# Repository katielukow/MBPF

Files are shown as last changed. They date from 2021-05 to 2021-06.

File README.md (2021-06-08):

# Modular Battery Pressure Fixture (MBPF)

**Background**

The High Voltage and Energy Storage Group (HVES) is a research group within the School of Engineering, Computing, and Mathematics at Oxford Brookes University. The group focuses is developing novel solutions to problems within the energy storage and future of transport fields. This includes multi-scale numerical modelling, electrochemical testing of lithium-ion batteries, and optimal control research for battery management and high-voltage powertrain systems. The group also has experience in optimal high power battery pack design and second-life applications of packs. Additional information can be found at https://hves.brookes.ac.uk. As part of the electrochemical testing, a fixture was designed to apply pressure to the outside faces of a lithium-ion pouch cell to provide a more accurate use case when completing cell level testing.

MBPF-Render-Asm

**Fixture Overview**

The fixture is a modular design that can accommodate cells that are 36mm to 50mm wide and 125mm to 145mm long. Pressure is applied to the cell through a double top plate that has Flexiforce sensors in between to map out the pressure distribution. A total of 14 M5 hex head screws are available to create the desired distribution based on the pressure and cell geometry being used. Nylon dowels are used to position the cell in place.

assemblyexplodedview

Two busbars are clamped onto the battery tabs with M6 bronze fasteners for current load and there is a gold-plated copper piece for voltage sensing. Current development is looking at creating additional lower bus bar designs to account for higher current loads with M8 fasteners.There is a grid system for thermocouples to be placed at various locations across the cell surface.

thermocouplechannel

**Exploded View & Bill of Materials**

An exploded view of the assembly can be found in the image below with a bill of materials available in the table below.

fullassemblyexploded
  
| Part Number | Part Name | Quantity |
| :---: | :---: | :---: |
| HVES-FIX-PRES-01  | Pouch Pressure Fixture - Top | 2 |
| HVES-FIX-PRES-02  | Pouch Pressure Fixture - Bottom | 1 |
| HVES-FIX-PRES-03  | Copper Clamp - Bottom | 2 |
| HVES-FIX-PRES-04  | Copper Clamp - Top | 2 |
| HVES-FIX-PRES-05  | Clamp Holder| 1 |
| HVES-FIX-PRES-07  | Voltage Sensing Plate | 2 |
| HVES-FIX-PRES-08  | Tab Separator | 1 |
| N/A  | M2.5X0.45 Grub Screw - 6mm Long | 8 |
| N/A  | M3X0.5 Button Head Cap Screw - 6mm Long | 2 |
| N/A  | M3X0.5 Button Head Cap Screw - 10mm Long | 8 |
| N/A  | M4X0.7 Button Head Cap Screw - 10mm Long | 4 |
| N/A  | M4X0.7 Hex Head Bolt - 60mm Long | 4-14 |
| N/A  | M4X0.7 Hex Nut | 4 |
| N/A  | M5X0.8 Button Head Cap Screw - 25mm Long | 1 |
| N/A  | M5X0.8 Hex Nut | 1 |
| N/A  | M6X1.0 Brass Hex Head Bolt - 25mm Long | 2 |
| N/A  | M6 Brass Spring Washer | 2 |
| N/A  | M6X1.0 Brass Hex Nut | 2 |
| N/A  | 3mm X 6mm Long Nylon Dowel | 7 |

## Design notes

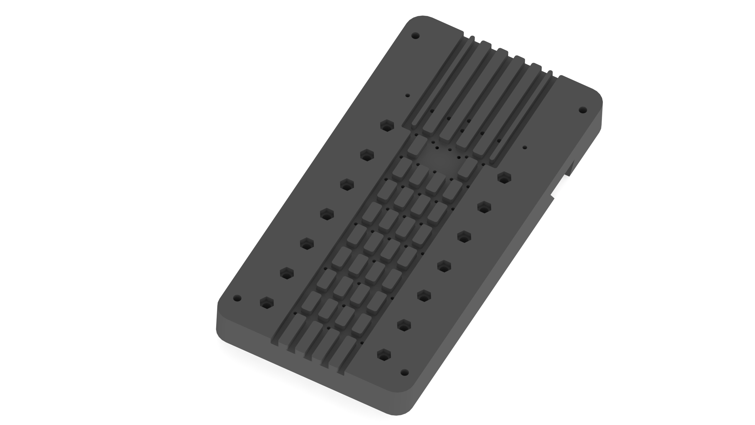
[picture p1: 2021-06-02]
renders/thermocouplechannel.jpg

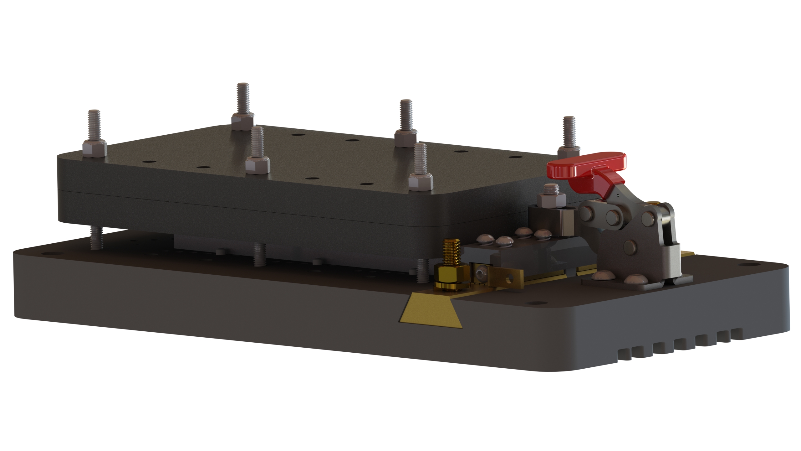
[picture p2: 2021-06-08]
renders/MBPF-Render-Asm.JPG

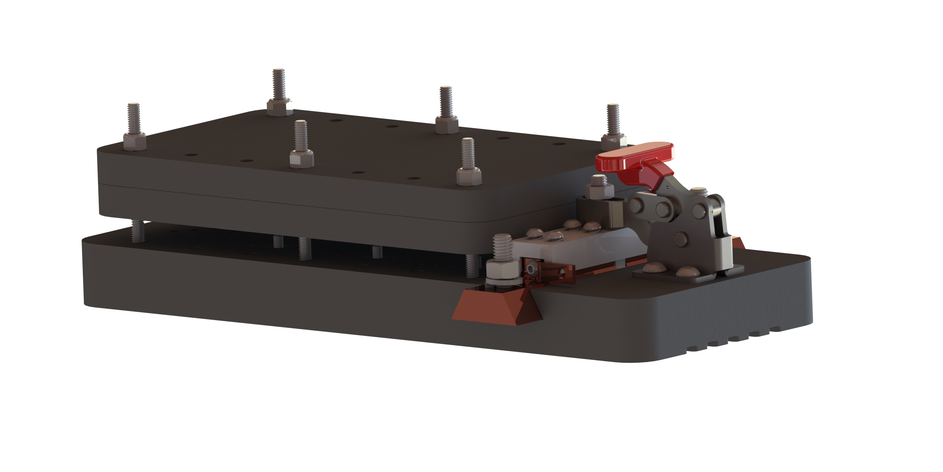
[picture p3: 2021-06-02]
renders/MBPF-Render.jpeg

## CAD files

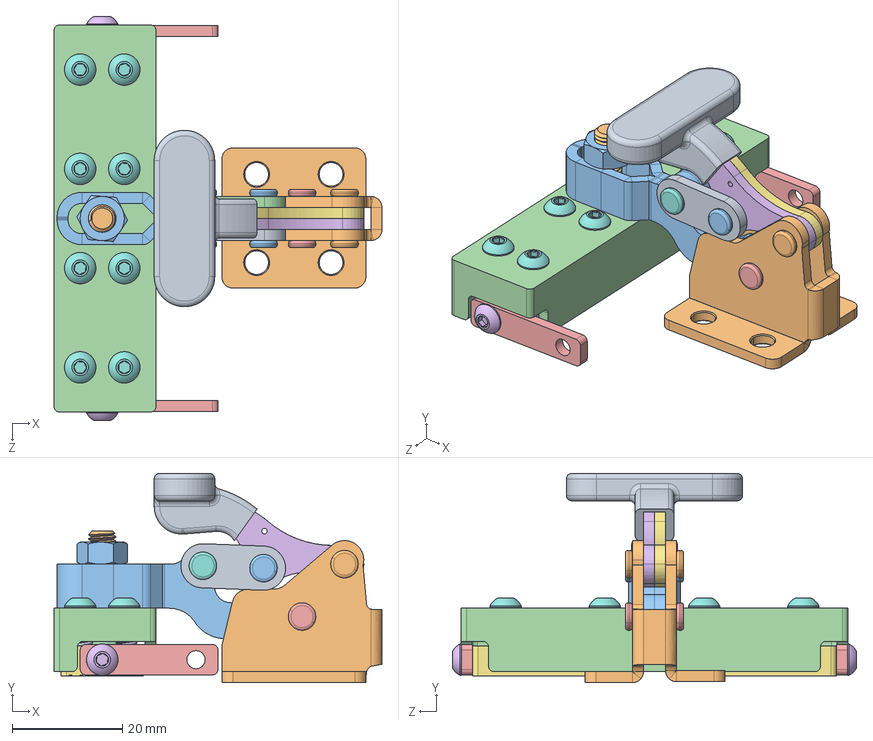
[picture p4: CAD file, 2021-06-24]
CAD/Toggle Clamp Sub Assembly.SLDASM
59.5 x 38.0 x 73.3 mm
Clamp Holder - Single
Voltage Sensing Plate - Flat x 2
92095A179_BUTTON HEAD HEX DRIVE SCREW x 2
Copper Clamp Top x 2
92095A182_BUTTON HEAD HEX DRIVE SCREW x 8
LeeSpring-LCM055B 02 M x 8
92095A481_BUTTON HEAD HEX DRIVE SCREW
90592A095_STEEL HEX NUT

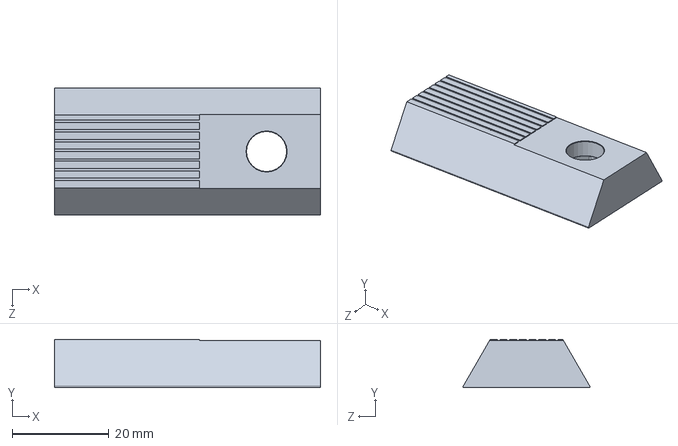
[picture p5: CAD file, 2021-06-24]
CAD/Copper Clamp Bottom.SLDPRT
55.0 x 10.0 x 26.2 mm

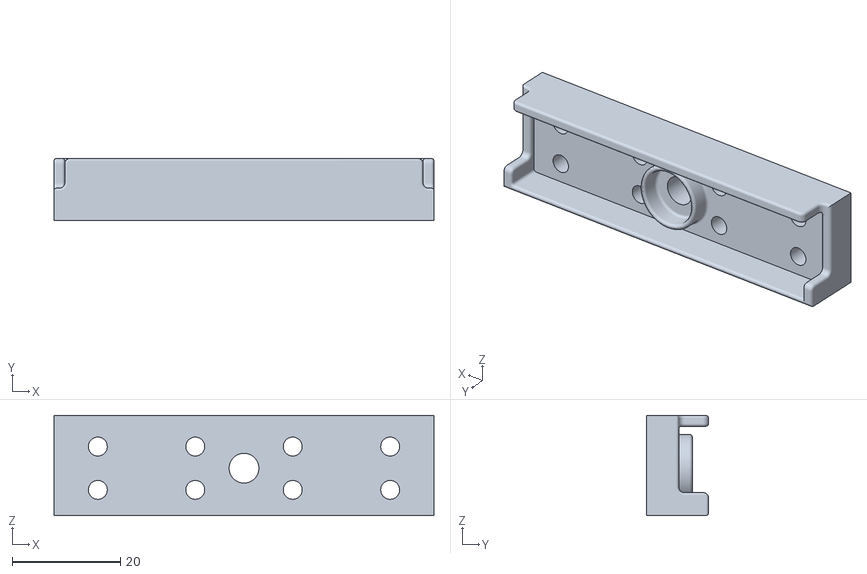
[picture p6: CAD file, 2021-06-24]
stl/HVES-FIX-PRES-05 R1.STL
70.2 x 11.5 x 18.5

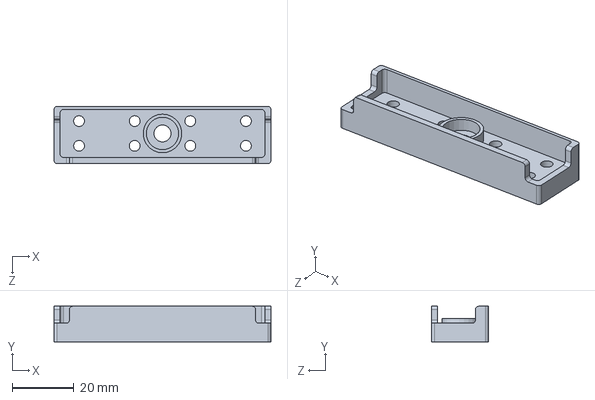
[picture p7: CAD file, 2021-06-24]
CAD/Clamp Holder - Single.SLDPRT
70.2 x 11.5 x 18.5 mm

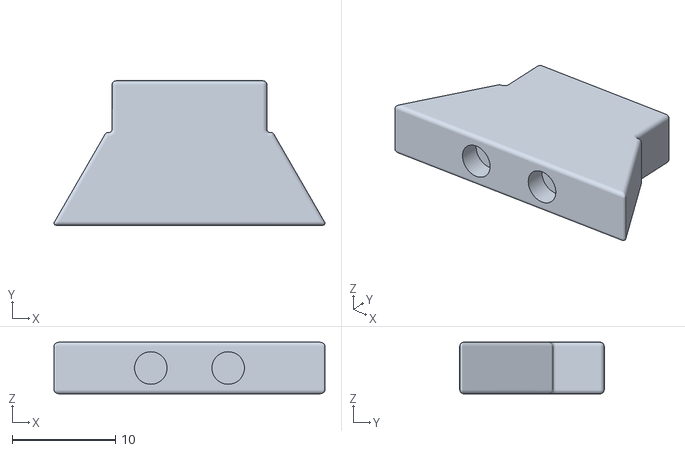
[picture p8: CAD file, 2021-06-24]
stl/HVES-FIX-PRES-08 R0.STL
26.2 x 14.0 x 5.00

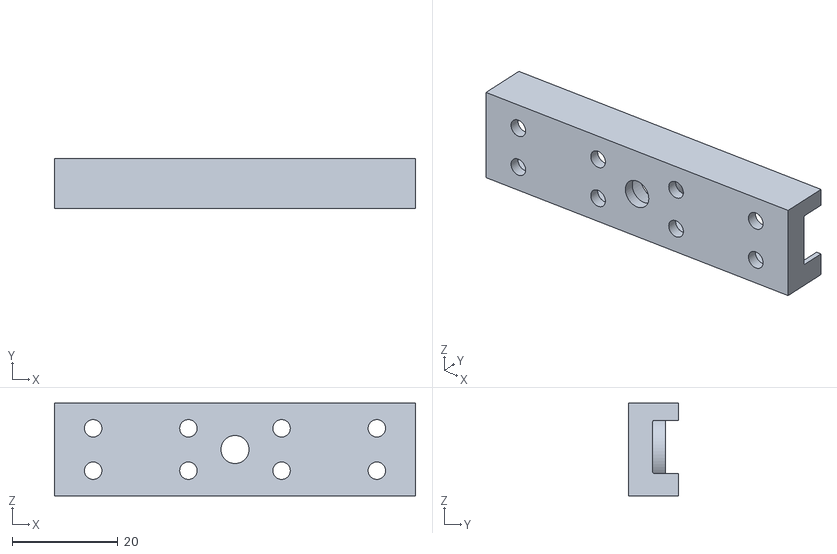
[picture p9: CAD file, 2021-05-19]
stl/HVES-FIX-PRES-05 R0.STL
68.2 x 9.50 x 17.5

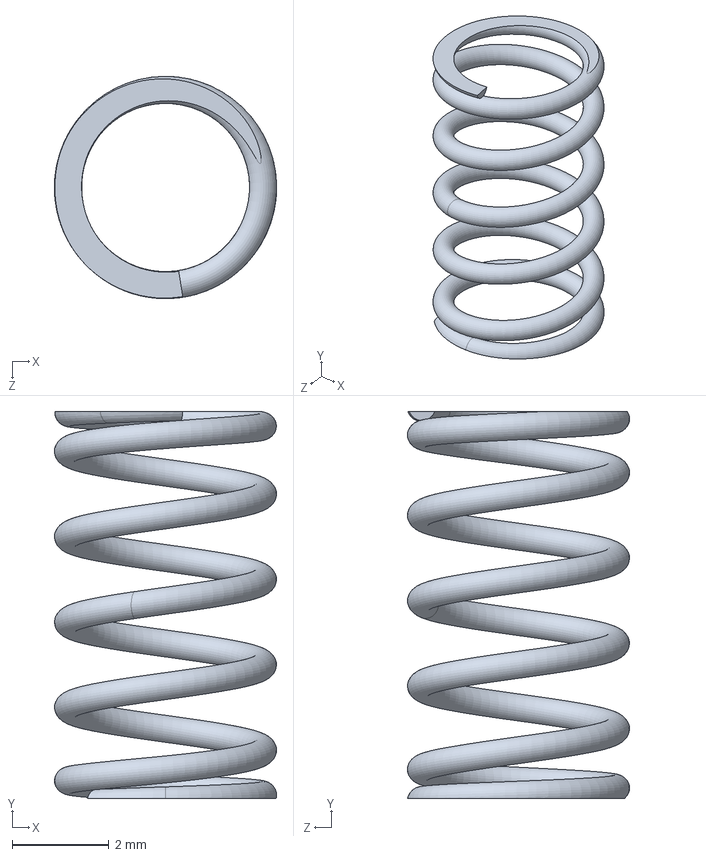
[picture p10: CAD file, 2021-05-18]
CAD/Fastener CAD/LeeSpring-LCM055B 02 M.SLDPRT
4.60 x 8.00 x 4.60 mm

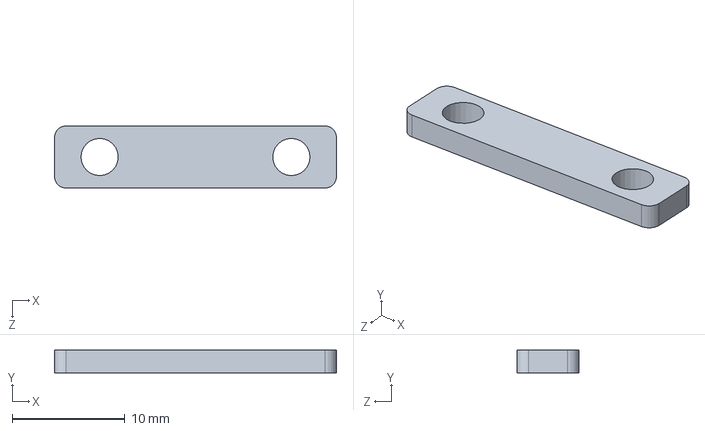
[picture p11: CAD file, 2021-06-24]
CAD/Voltage Sensing Plate - Flat.SLDPRT
25.0 x 2.00 x 5.50 mm

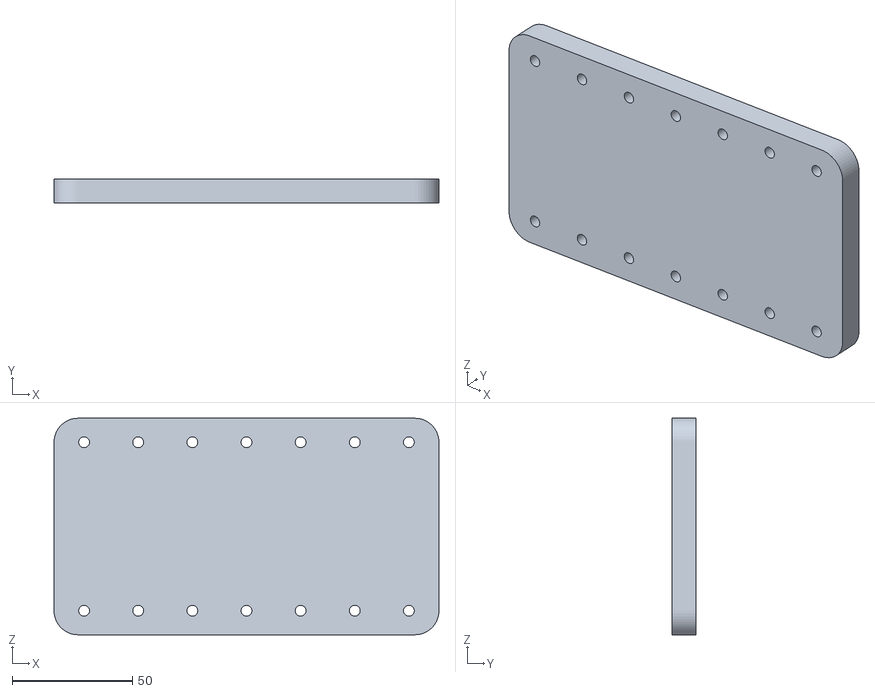
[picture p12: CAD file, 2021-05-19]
stl/HVES-FIX-PRES-01 R0.STL
160.0 x 10.0 x 90.0

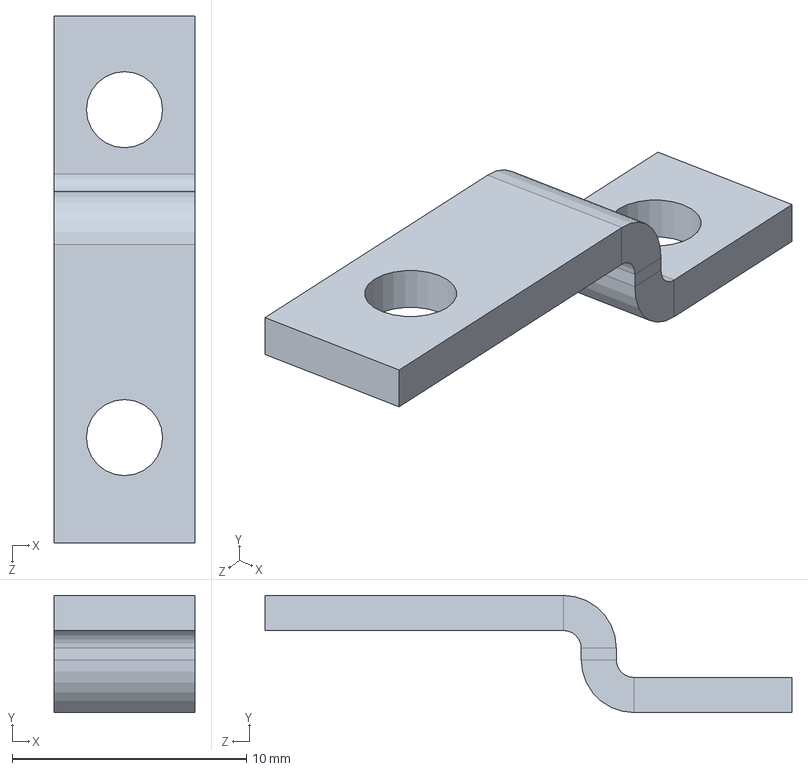
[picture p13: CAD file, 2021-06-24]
CAD/Voltage Sensing Plate.SLDPRT
6.00 x 5.00 x 22.5 mm

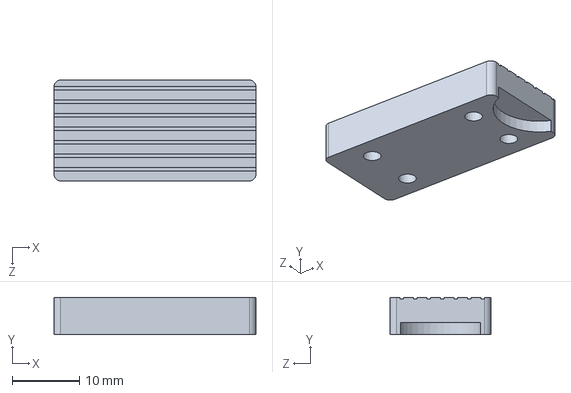
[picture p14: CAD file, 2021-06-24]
CAD/Copper Clamp Top.SLDPRT
30.0 x 5.50 x 15.0 mm

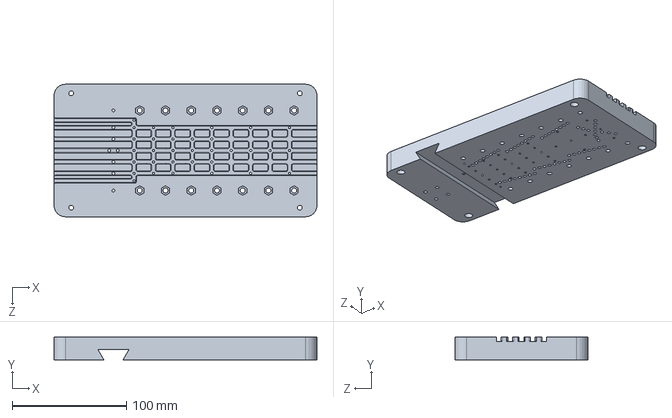
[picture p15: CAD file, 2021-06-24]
CAD/Pouch Pressure Fixture Base.SLDPRT
230.0 x 20.0 x 116.0 mm

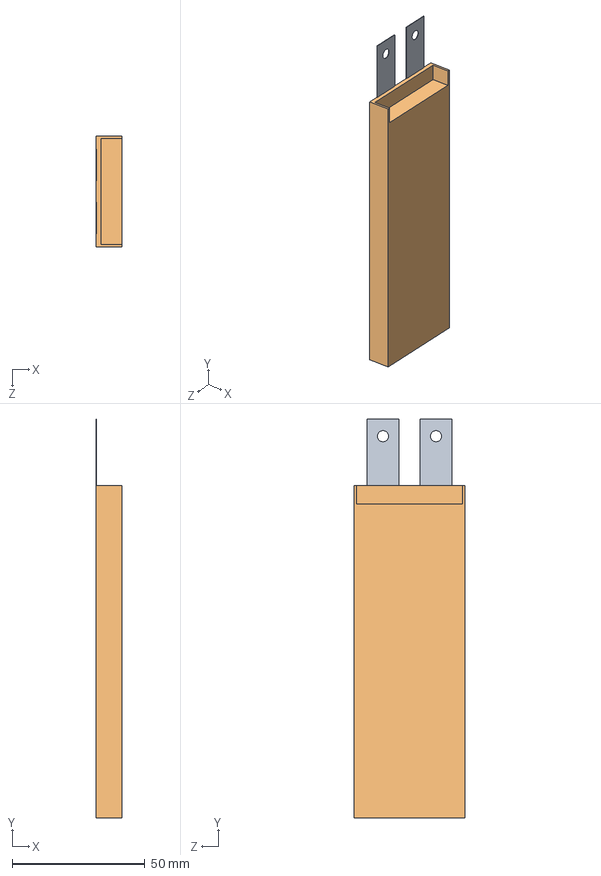
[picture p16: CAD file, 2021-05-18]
CAD/OBR21_ELT_00251_Testing_Cell.STEP
9.90 x 150.5 x 41.8 mm

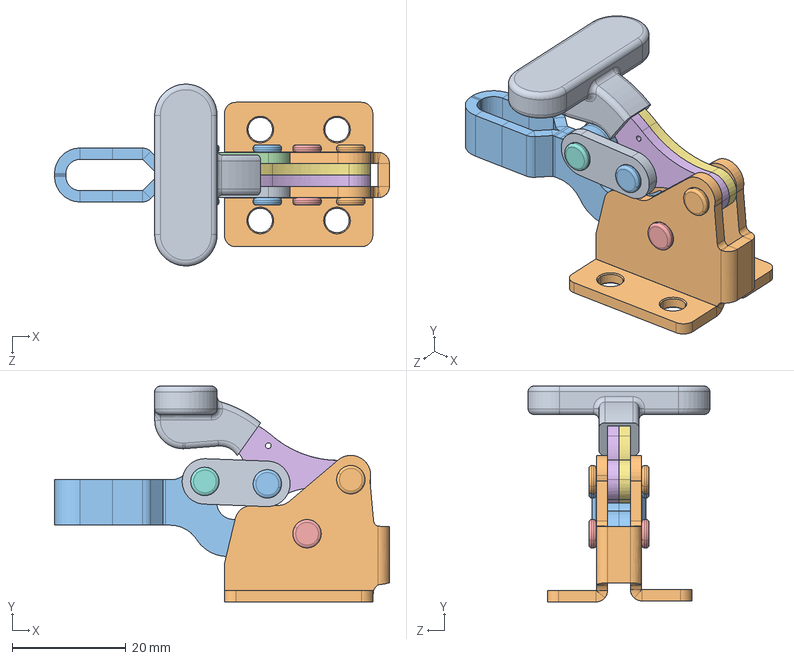
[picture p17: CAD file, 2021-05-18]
CAD/Toggle Clamp CAD/1472804.SLDASM
58.9 x 38.0 x 32.0 mm

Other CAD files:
CAD/Tab Separator.SLDPRT
CAD/Pouch Pressure Fixture Top.SLDPRT
CAD/Fastener CAD/90690A047_BRASS HEX NUT.SLDPRT
CAD/Toggle Clamp CAD/1472804_16.SLDPRT
CAD/Clamp Holder - Single.SLDDRW
CAD/Copper Clamp Bottom.SLDDRW
CAD/Copper Clamp Top.SLDDRW
CAD/Fastener CAD/90592A095_STEEL HEX NUT.SLDPRT
CAD/Fastener CAD/91287A060_18-8 STAINLESS STEEL HEX HEAD SCREW.SLDPRT
CAD/Fastener CAD/91310A333_HIGH-STRG UNCOATED STL CAP SCREW - CLASS 10.9.SLDPRT
CAD/Fastener CAD/91390A256_ALLOY STEEL CUP POINT SET SCREW.SLDPRT
CAD/Fastener CAD/91595A100_METRIC ALLOY STEEL DOWEL PIN.SLDPRT
CAD/Fastener CAD/92095A179_BUTTON HEAD HEX DRIVE SCREW.SLDPRT
CAD/Fastener CAD/92095A182_BUTTON HEAD HEX DRIVE SCREW.SLDPRT
CAD/Fastener CAD/92095A190_BUTTON HEAD HEX DRIVE SCREW.SLDPRT
CAD/Fastener CAD/92095A481_BUTTON HEAD HEX DRIVE SCREW.SLDPRT
CAD/Fastener CAD/92148A180_TYPE 18-8 STAINLESS STEEL SPLIT LOCK WASHER.SLDPRT
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

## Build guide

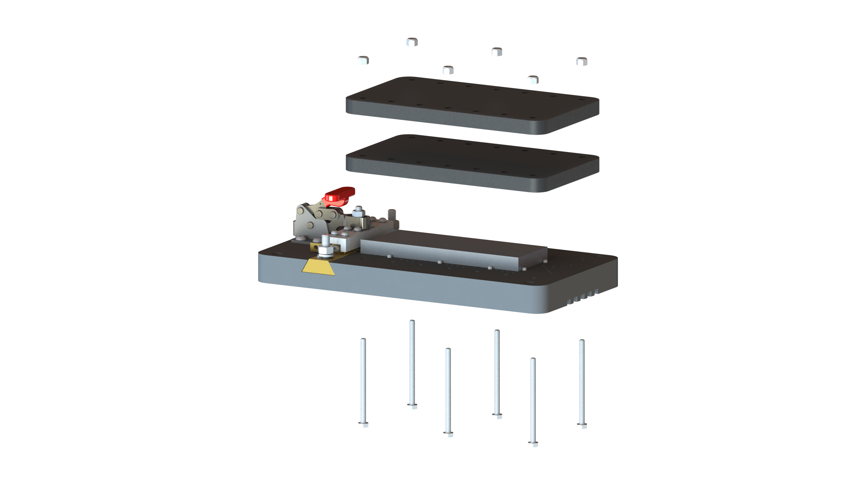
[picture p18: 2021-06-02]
renders/assemblyexplodedview.jpeg

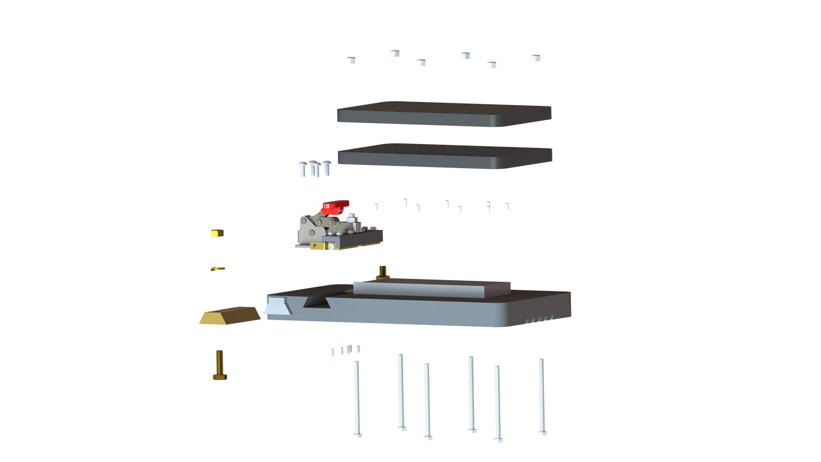
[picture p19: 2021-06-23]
renders/fullassemblyexploded.jpg

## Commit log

2021-05-19 Added stl files
    [HVES-FIX-PRES-01 R0.STL, HVES-FIX-PRES-05 R0.STL]
2021-05-24 edit folder structure
    [1472804.SLDASM, 1472804_02.SLDPRT, 1472804_03.SLDPRT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]
2021-05-26 Added renders, modified exploded views
    [OBR21_ELT_00251_Testing_Cell.SLDPRT, Pouch Pressure Fixture Asm - Single Clamp.SLDDRW, Pouch Pressure Fixture Base.SLDPRT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]
2021-05-26 Added set screws, corrected asm exploded view
    [90690A047_BRASS HEX NUT.SLDPRT, 91310A333_HIGH-STRG UNCOATED STL CAP SCREW - CLASS 10.9.SLDPRT, 92148A180_TYPE 18-8 STAINLESS STEEL SPLIT LOCK WASHER.SLDPRT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]
2021-05-28 Restructure folders, added Pack and Go
    [1472804.SLDASM, 1472804_02.SLDPRT, 1472804_03.SLDPRT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]
2021-05-28 Assembly updates
    [Pouch Pressure Fixture Asm - Single Clamp.SLDDRW, Toggle Clamp Sub Assembly.SLDASM]
2021-06-01 Added BOM to readme
2021-06-02 Updated material properties and exploded views
    [90690A047_BRASS HEX NUT.SLDPRT, 91310A333_HIGH-STRG UNCOATED STL CAP SCREW - CLASS 10.9.SLDPRT, 92148A180_TYPE 18-8 STAINLESS STEEL SPLIT LOCK WASHER.SLDPRT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]
2021-06-02 Updated dwg approvals
    [Clamp Holder - Single.SLDDRW, Copper Clamp Bottom.SLDDRW, Copper Clamp Top.SLDDRW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]
2021-06-24 Modified top clamp for voltage sensing, changed slots to hex in base plate
    [Clamp Holder - Single.SLDDRW, Clamp Holder - Single.SLDPRT, Copper Clamp Top.SLDPRT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]
2021-06-24 Updated 05 for machining, minor changes after initial prototype
    [Clamp Holder - Single.SLDDRW, Clamp Holder - Single.SLDPRT, Copper Clamp Bottom.SLDPRT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]
